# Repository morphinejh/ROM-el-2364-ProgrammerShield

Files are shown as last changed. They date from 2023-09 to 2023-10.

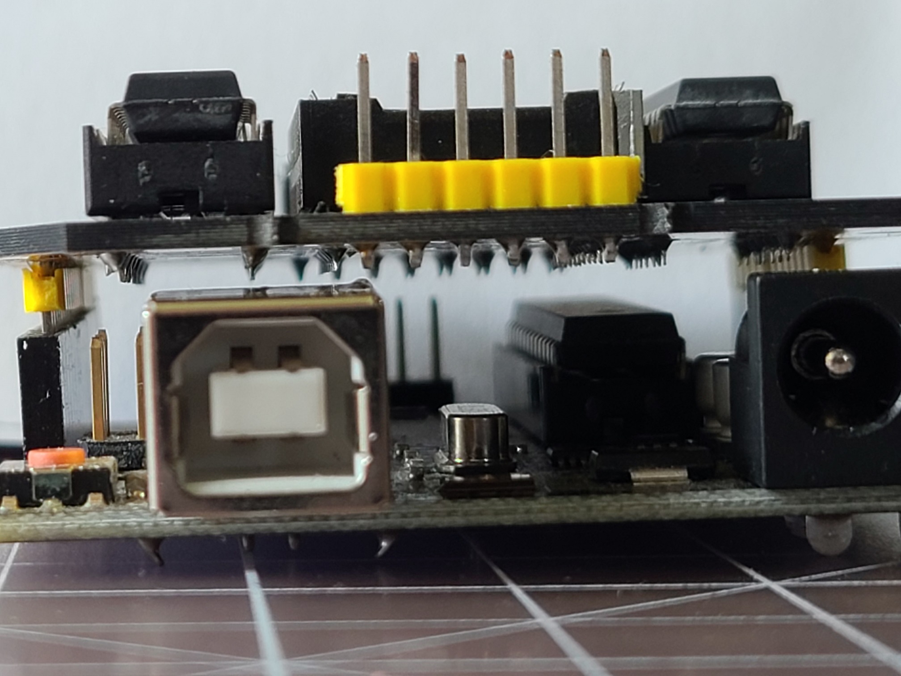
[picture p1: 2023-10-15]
Photos/ROM-el_2364_ClosUp.jpg

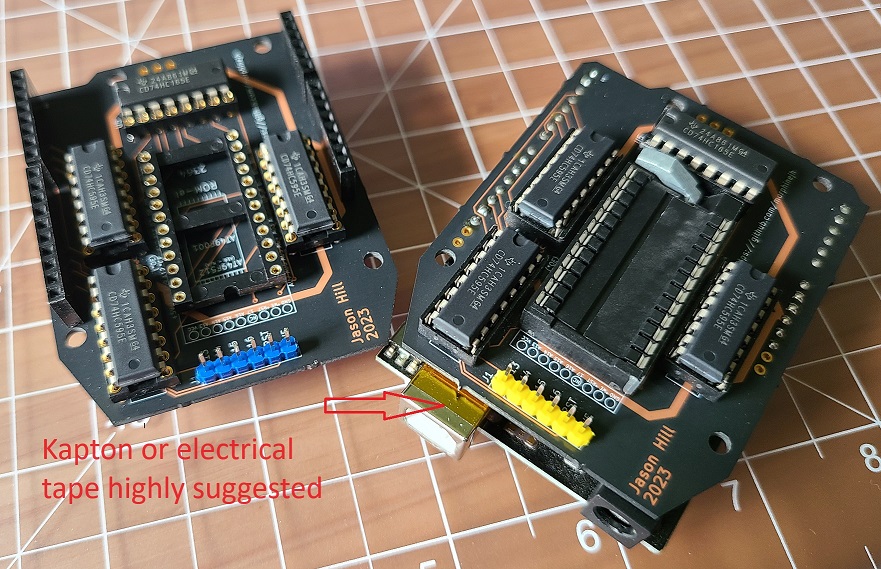
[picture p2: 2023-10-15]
Photos/ROM-el_2364 ProgrammerShield .jpg

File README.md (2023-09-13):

# Arduino Shield Programmer for ROM-el 2364
## Updates / Changes September 2023
* Added schematic for Arduino Shield
    * Test on: Duemilanove, Uno R3, and Mega R3
* Updated Arduino code and Python script data types to extend them to 32-bits for AT49F001 which has 17-bit addressing for the full range.
    * Added basic time duration to displayed output
    * Pin header to attach address
* Tested on Windows and Linux with Python 3
    * Comm port address is now a variable
* [Shared on OSH park](https://oshpark.com/shared_projects/amO60ueQ)

# ROM-el 2364 Programmer

This is an Arduino sketch and companion Python application to read from and write to ROM-el 2364 devices that (as of June 2018) ship with the AT49F512 EEPROM chip. It should, however ,also work with the AT49F001 EEPROM that was originally shipped on the ROM-el 2364.

The Python script was written and tested on a Linux system, and may need some tweaks to run in Windows environments, such as changing the serial port in the init_arduino() routine from /dev/ttyACM0 to, i.e. COM1.

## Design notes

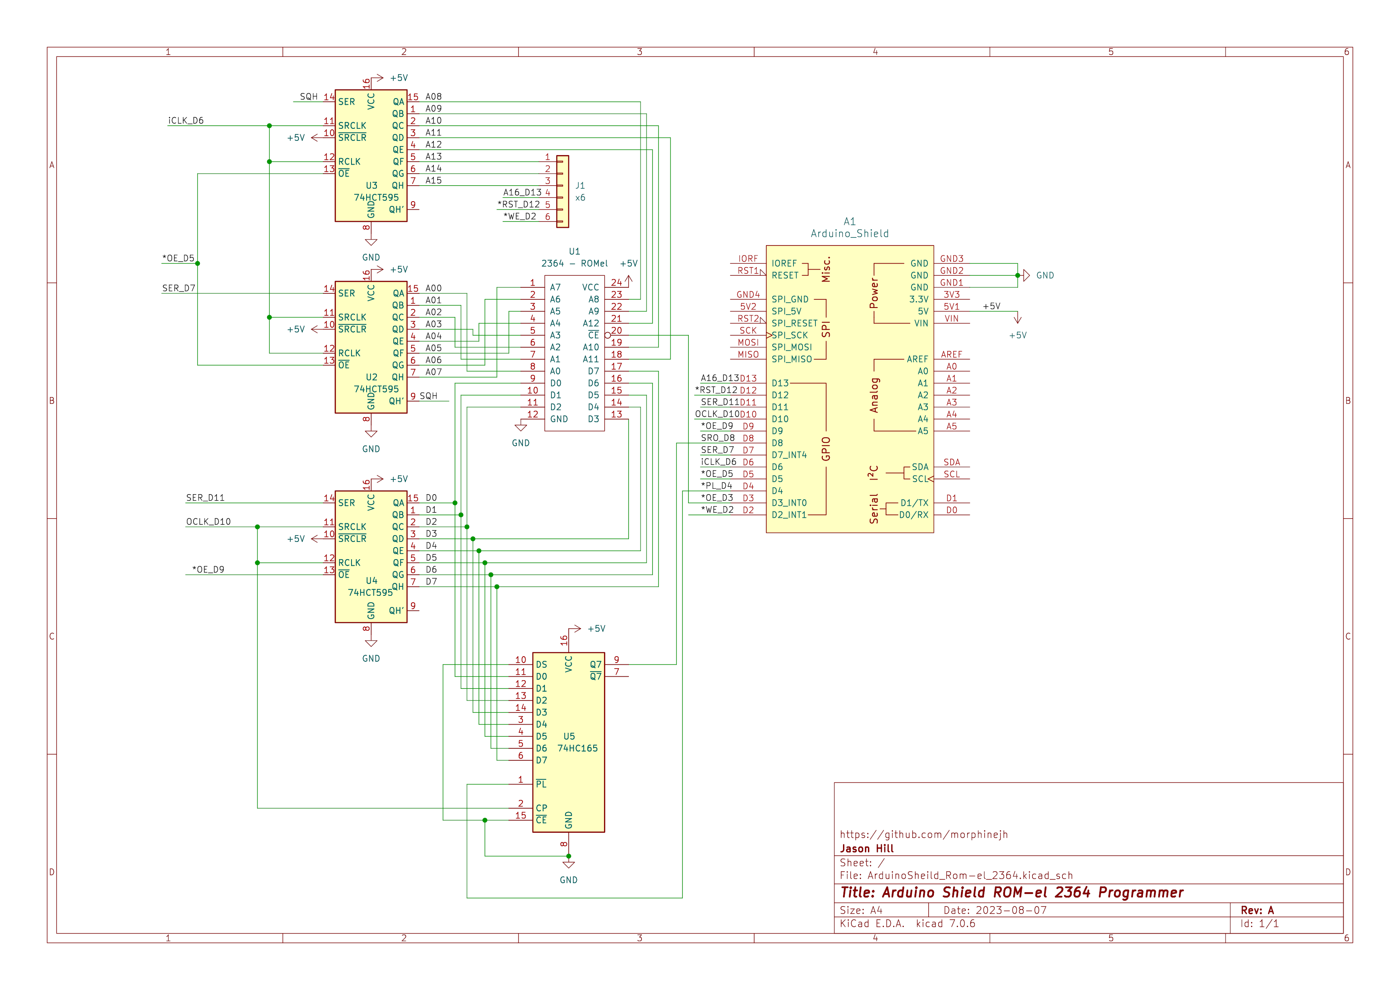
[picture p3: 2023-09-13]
ArduinoSheild_Schematic.png

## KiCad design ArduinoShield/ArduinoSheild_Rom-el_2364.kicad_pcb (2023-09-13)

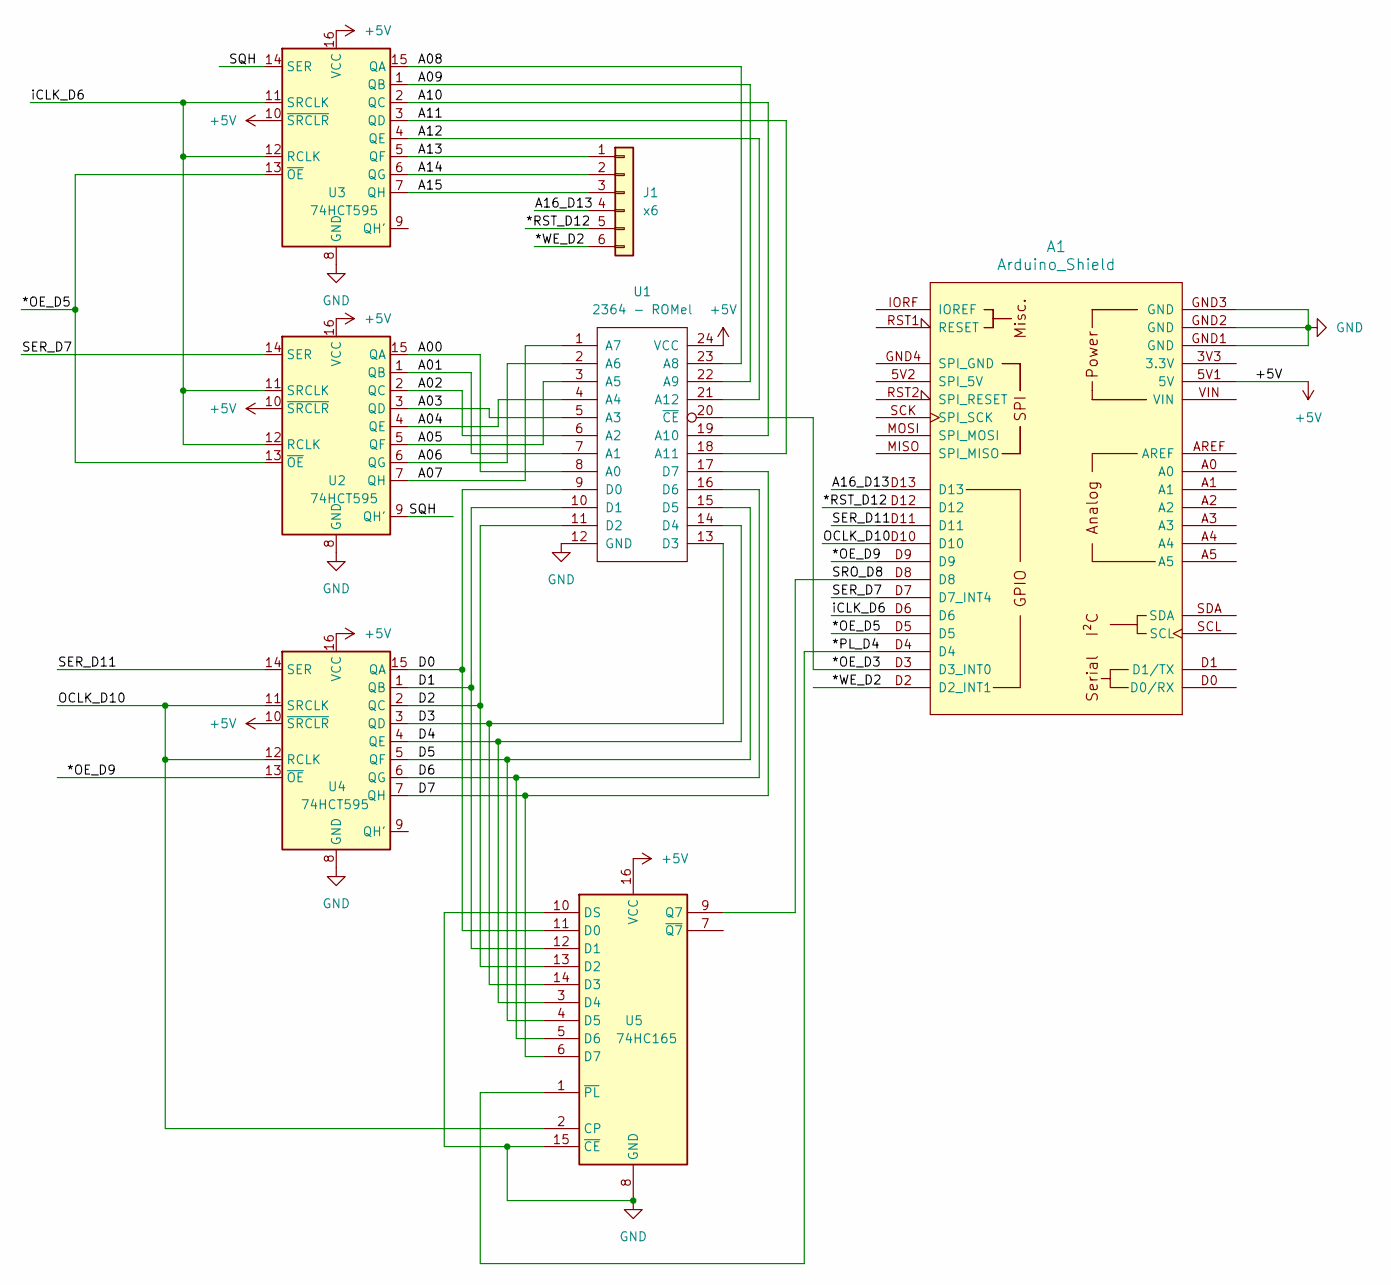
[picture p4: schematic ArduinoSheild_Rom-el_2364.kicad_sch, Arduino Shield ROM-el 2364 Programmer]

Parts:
A1: Arduino_Shield; Arduino_Leonardo_Shield
J1: x6; PinHeader_1x06_P2.54mm_Vertical
U1: 2364 - ROMel; DIP-24_W15.24mm-Notch
U2, U3, U4: 74HCT595; DIP-16_W7.62mm
U5: 74HC165; DIP-16_W7.62mm

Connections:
+5V: A1.5V1 (5V), U1.24 (VCC), U2.10 (~SRCLR), U2.16 (VCC), U3.10 (~SRCLR), U3.16 (VCC), U4.10 (~SRCLR), U4.16 (VCC), U5.16 (VCC)
/*CE_D3: A1.D3 (D3_INT0), U1.20 (~CE)
/*OE_D5: A1.D5, U2.13 (~OE), U3.13 (~OE)
/*OE_D9: A1.D9, U4.13 (~OE)
/*PL_D4: A1.D4, U5.1 (~PL)
/*RST_D12: A1.D12, J1.5
/*WE_D2: A1.D2 (D2_INT1), J1.6
/A00: U1.8 (A0), U2.15 (QA)
/A01: U1.7 (A1), U2.1 (QB)
/A02: U1.6 (A2), U2.2 (QC)
/A03: U1.5 (A3), U2.3 (QD)
/A04: U1.4 (A4), U2.4 (QE)
/A05: U1.3 (A5), U2.5 (QF)
/A06: U1.2 (A6), U2.6 (QG)
/A07: U1.1 (A7), U2.7 (QH)
/A08: U1.23 (A8), U3.15 (QA)
/A09: U1.22 (A9), U3.1 (QB)
/A10: U1.19 (A10), U3.2 (QC)
/A11: U1.18 (A11), U3.3 (QD)
/A12: U1.21 (A12), U3.4 (QE)
/A13: J1.1, U3.5 (QF)
/A14: J1.2, U3.6 (QG)
/A15: J1.3, U3.7 (QH)
/A16_D13: A1.D13, J1.4
/D0: U1.9 (D0), U4.15 (QA), U5.11 (D0)
/D1: U1.10 (D1), U4.1 (QB), U5.12 (D1)
/D2: U1.11 (D2), U4.2 (QC), U5.13 (D2)
/D3: U1.13 (D3), U4.3 (QD), U5.14 (D3)
/D4: U1.14 (D4), U4.4 (QE), U5.3 (D4)
/D5: U1.15 (D5), U4.5 (QF), U5.4 (D5)
/D6: U1.16 (D6), U4.6 (QG), U5.5 (D6)
/D7: U1.17 (D7), U4.7 (QH), U5.6 (D7)
/OCLK_D10: A1.D10, U4.11 (SRCLK), U4.12 (RCLK), U5.2 (CP)
/SER_D7: A1.D7 (D7_INT4), U2.14 (SER)
/SER_D11: A1.D11, U4.14 (SER)
/SQH: U2.9 (QH'), U3.14 (SER)
/SRO_D8: A1.D8, U5.9 (Q7)
/iCLK_D6: A1.D6, U2.11 (SRCLK), U2.12 (RCLK), U3.11 (SRCLK), U3.12 (RCLK)
GND: A1.GND1 (GND), A1.GND2 (GND), A1.GND3 (GND), U1.12 (GND), U2.8 (GND), U3.8 (GND), U4.8 (GND), U5.8 (GND), U5.10 (DS), U5.15 (~CE)

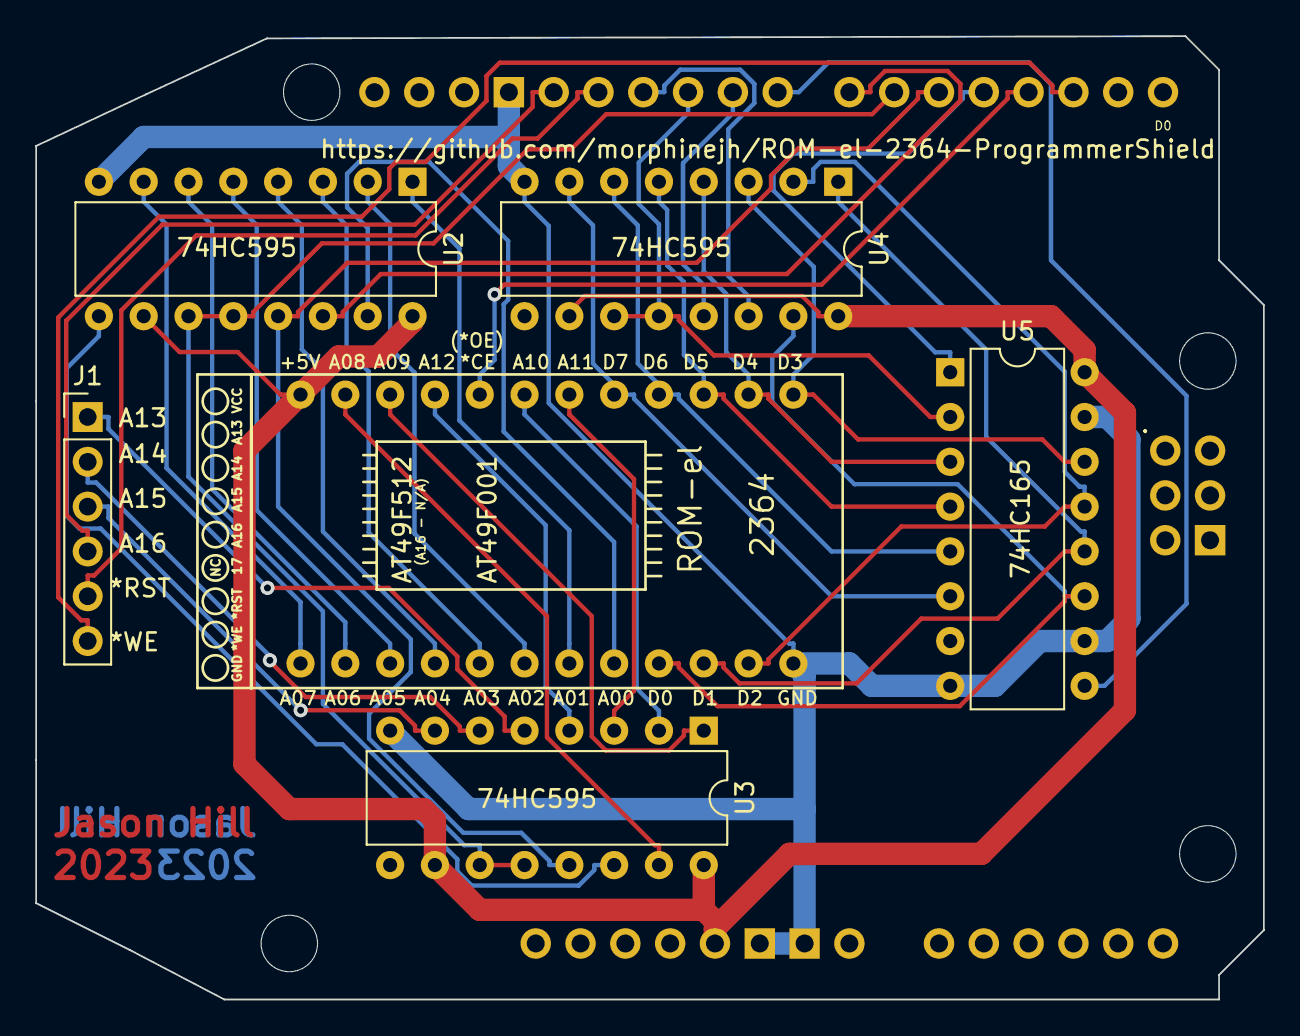
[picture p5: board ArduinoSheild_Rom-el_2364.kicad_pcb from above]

Board: 2 copper layers, 69.6 x 54.6 mm, 7 parts (0 on the bottom side), 39 nets.

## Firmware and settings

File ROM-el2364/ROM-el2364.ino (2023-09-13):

#include "ROM-el2364.hpp"

Mode mode = READ;

void printMessage(String message){
  Serial.write(message.length()+2);
  Serial.println(message);
}

void setup() {
  pinMode(ADDROE, OUTPUT);
  digitalWrite(ADDROE, HIGH);
  pinMode(ADDRCLK, OUTPUT);
  digitalWrite(ADDRCLK, LOW);
  pinMode(ADDRSER, OUTPUT);
  digitalWrite(ADDRSER, LOW);
  pinMode(DATAINOE, OUTPUT);
  digitalWrite(DATAINOE, LOW);
  pinMode(DATAOUTOE, OUTPUT);
  digitalWrite(DATAOUTOE, HIGH);
  pinMode(DATACLK, OUTPUT);
  digitalWrite(DATACLK, LOW);
  pinMode(DATAOUTSER, OUTPUT);
  digitalWrite(DATAOUTSER, LOW);
  pinMode(DATAINSER, INPUT_PULLUP);
  pinMode(EEPROMOE, OUTPUT);
  digitalWrite(EEPROMOE, HIGH);
  pinMode(EEPROMWE, OUTPUT);
  digitalWrite(EEPROMWE, HIGH);

  pinMode(RSTROMEL, OUTPUT);
  digitalWrite(RSTROMEL, HIGH);
  pinMode(ADDR16, OUTPUT);
  digitalWrite(ADDR16, HIGH);

  Serial.begin(115200);
  Serial.setTimeout(3000);
  Serial.print("INIT");
  //Let's do some byte transfers!
}

void setReadMode(){
  if( mode == READ )
    return;
  //Disable shift register (write)
  DATAOUTOE_Set(HIGH);//digitalWrite(DATAOUTOE, HIGH);
  mode = READ;
}

void setWriteMode(){
  if( mode == WRITE )
    return;
  //Disable shift-in register (read)
  DATAINOE_Set(LOW);//digitalWrite(DATAINOE, LOW);
  mode = WRITE;
}

//Shift byte out to SN74HC595 (with tied data lines)
void shiftByteOut(byte data, bool noclock, int clkpin, int serpin, int oepin)
{
  if( oepin == DATAOUTOE )
    digitalWrite(DATAOUTOE, HIGH);
  else
    digitalWrite(oepin, HIGH);

  byte tmpdata = data;

  //Shift MSB-first
  for ( int i = 0; i < 8; i++ )
  {
    digitalWrite(serpin, tmpdata >> 7);
    digitalWrite(clkpin, HIGH);
    digitalWrite(clkpin, LOW);
    tmpdata = tmpdata << 1;
  }
  digitalWrite(serpin, LOW);
  //With tied clock lines, an additional clock pulse is necessary after shifting
  //the very last bit to all shift registers in order to output expected data.
  if(! noclock)
  {
    //Additional clock due to tied RCLK/SRCLK lines
    digitalWrite(clkpin, HIGH);
    digitalWrite(clkpin, LOW);
  }
  if( oepin == DATAOUTOE )
    digitalWrite(DATAOUTOE, LOW);
  else
    digitalWrite(oepin, LOW);
}

//Shift byte in from SN74HC165
uint8_t shiftByteIn(int clkpin, int serpin, int latchpin, short bits = 8){//return shiftByteIn(DATACLK, DATAINSER, DATAINOE, bits);
  uint8_t input = 0;
  DATACLK_Set(HIGH);//digitalWrite(clkpin, HIGH);

  if( latchpin == DATAINOE )
    DATAINOE_Set(LOW);//digitalWrite(DATAINOE, LOW);
  else
    digitalWrite(latchpin, LOW);

  if( latchpin == DATAINOE )
    DATAINOE_Set(HIGH);//digitalWrite(DATAINOE, HIGH);
  else
    digitalWrite(latchpin, HIGH);
    
  //Data shift in MSB-first
  for ( int i = 0; i < bits; i++ ){
    DATACLK_Set(HIGH);//digitalWrite(clkpin, HIGH);
    //Don't clock first, 74HC165 outputs first byte as soon as latch goes high
    __builtin_avr_delay_cycles(5);//TODO: Possible less delay
    input |= DATAINSER_Read() << ((bits-1)-i);//input |= digitalRead(serpin) << ((bits-1)-i);
    DATACLK_Set(LOW);//digitalWrite(clkpin, LOW);
  }
  DATAINOE_Set(LOW);//digitalWrite(DATAINOE, LOW);
  return input;
}

//Write to address lines
void shiftAddress(uint32_t addrin){
  uint16_t addr = addrin & 0x0000FFFF;
  uint8_t out[2];

  out[0]=(addr>>8)&0xFF;
  out[1]=0xFF&addr;

  if(addrin > 0xFFFF){
    digitalWrite(ADDR16,HIGH);
  }
  else{
    digitalWrite(ADDR16,LOW);
  }

  shiftByteOut(out[0], true, ADDRCLK, ADDRSER, ADDROE);
  shiftByteOut(out[1], false, ADDRCLK, ADDRSER, ADDROE);
}

//Write to data lines
void shiftData(uint8_t data){
  setWriteMode();
  shiftByteOut(data, false, DATACLK, DATAOUTSER, DATAOUTOE);
}

//Shift data lines in
//Arguments:
//bits: How many bits to shift in (useful in waitForToggleBit() so that cycles
//      aren't wasted shifting in bits we don't care about.)
uint8_t shiftInData(short bits = 8){
  setReadMode();
  return shiftByteIn(DATACLK, DATAINSER, DATAINOE, bits);
}

//Never could get this to work properly, but waitForToggleBit() works, so...
/*void dataPoll(unsigned short addr, byte data)
{
  setReadMode();
  digitalWrite(EEPROMOE, LOW);
  __builtin_avr_delay_cycles(1);
  bool validdata = data & 0x80;
  while( true )
  {
    digitalWrite(EEPROMOE, LOW);
    byte addressread = shiftInData();
    addressread &= 0x80;
    digitalWrite(EEPROMOE, HIGH);
    if( addressread != validdata )
      continue;
    else
      break;
  }
}*/

//Implementation of "AC Load" from AT49F512 datasheet
void ACLoad(uint32_t addrin, uint8_t data){
  setWriteMode();
  EEPROMOE_Set(HIGH);//digitalWrite(EEPROMOE, HIGH);
  shiftAddress(addrin);
  EEPROMWE_Set(LOW);//digitalWrite(EEPROMWE, LOW);
  __builtin_avr_delay_cycles(2); //Delay an extra cycle to satisfy tWP = 90ns
  shiftData(data);
  EEPROMWE_Set(HIGH);//digitalWrite(EEPROMWE, HIGH);
  __builtin_avr_delay_cycles(2); //Delay cycles to satisfy tWPH = 90ns
}

//Implementation of "AC Read" from AT49F512 datasheet
uint8_t ACRead(uint32_t addrin){
  setReadMode();
  EEPROMWE_Set(HIGH);//digitalWrite(EEPROMWE, HIGH);
  shiftAddress(addrin);
  EEPROMOE_Set(LOW);//digitalWrite(EEPROMOE, LOW);
  __builtin_avr_delay_cycles(2);
  uint8_t input = shiftInData();
  EEPROMOE_Set(HIGH);//digitalWrite(EEPROMOE, HIGH);
  return input;
}

uint8_t writeAddress(uint32_t addrin, uint8_t data){
  ACLoad(0x5555, 0xAA);
  ACLoad(0x2AAA, 0x55);
  ACLoad(0x5555, 0xA0);
  ACLoad(addrin, data);
  digitalWrite(EEPROMOE, LOW);
  waitForToggleBit();
  return 0x00;
}

void eraseChip(){
  digitalWrite(EEPROMOE, HIGH);
  ACLoad(0x5555, 0xAA);
  ACLoad(0x2AAA, 0x55);
  ACLoad(0x5555, 0x80);
  ACLoad(0x5555, 0xAA);
  ACLoad(0x2AAA, 0x55);
  ACLoad(0x5555, 0x10);
  waitForToggleBit();
}

//This Atmel chip, during a program or erase cycle will implement a "toggle bit."
//Per the datasheet:
//"During a program or erase operation, successive attempts to read data from the device
//will result in I/O6 toggling between one and zero. Once the program cycle has completed,
//I/O6 will stop toggling and valid data will be read."
void waitForToggleBit(){
  return;
  uint8_t initial = 0;
  uint8_t nextbit = 0;
  setReadMode();
  EEPROMOE_Set(LOW);//digitalWrite(EEPROMOE, LOW);
  //Store bit 7 (I/O 6)
  //byte initial = shiftInData(2) & 0x40;
  initial = shiftInData(2) & 0x40;
  while( true ){
    EEPROMOE_Set(HIGH);//digitalWrite(EEPROMOE, HIGH);

    //Needs to be high for 150ns, One cycle is ~62.5ns
    //At 16MHz this is a delay of ~187.5ns
    //However, a digital write already takes 3.4us = 3,400ns!!
    //dont' wait.
    __builtin_avr_delay_cycles(3);
    EEPROMOE_Set(LOW);//digitalWrite(EEPROMOE, LOW);
    
    //Check bit 7 again
    nextbit = shiftInData(2) & 0x40;
    //If bit 7 is stable, the write/erase has finished.
    if( nextbit == initial )
      break;
    else
      initial = nextbit;
  }
}

void verifyRange(uint32_t startaddr, uint32_t endaddr){
  for (uint32_t i = startaddr; i <= endaddr; i++ )
  {
    Serial.write(0x01);
    Serial.write(ACRead(i));
  }
}

void loop() {
  uint8_t data;
  uint8_t serialbuffer[10];
  memset(serialbuffer, 0x00, sizeof(serialbuffer));
  /*Protocol definition:
  <packet> ::= <length> <command> | <length> <command> <data>
  <data> ::= <address> | <address> <byte>
  <command> ::= 'R' | 'W' | 'E' comment <erase command>
  <byte> ::= <a single byte>
  <address> ::= <4-byte address>
  <length> ::= <1-byte length of packet (excluding length byte itself)>

  This allows two modes of operation:
  In the first mode (i.e. <length>R\x01\x00), the controlling application
  specifies all addresses (and, in write mode, the data to be stored). In the
  second mode (i.e. <length>R) bytes are read/written sequentially, using the
  address variable stored on the Arduino.

  If a program wanted to read 8 bytes starting at 0x0100, either of these
  command sets could be used:
  R\x01\x00
  R\x01\x01
  R\x01\x02
  R\x01\x03
  R\x01\x04
  R\x01\x05
  R\x01\x06
  R\x01\x07

  or

  R\x01\x00 //Read 7 sequential addresses
  R
  R
  R
  R
  R
  R
  R
  */

  while ( !Serial.available() )
    continue;

  Serial.readBytes(serialbuffer, 1);
  uint8_t packetlen = serialbuffer[0];

  while ( Serial.available() != packetlen )
    continue;

  Serial.readBytes(serialbuffer, packetlen);

  //Read mode
  if ( serialbuffer[0] == 'R' ){
    setReadMode();
    //No address given
    if ( packetlen == 1 ){
      data = ACRead(address);
      Serial.write(0x01);
      Serial.write(data);
    }
    //Address given
    else{
      uint32_t packetaddress = serialbuffer[1];
      packetaddress <<= 8;
      packetaddress += serialbuffer[2];
      packetaddress <<= 8;
      packetaddress += serialbuffer[3];
      packetaddress <<= 8;
      packetaddress += serialbuffer[4];
      address = packetaddress;

      data = ACRead(packetaddress);
      Serial.write(0x01);
      Serial.write(data);
    }
    address++;
  }
  //Write mode
  else if ( serialbuffer[0] == 'W' ){
    unsigned short retval;
    setWriteMode();
    //No address given
    if ( packetlen == 2 ){
      retval = writeAddress(address, serialbuffer[1]);
    }
    //Address given
    else{
      uint32_t packetaddress = serialbuffer[1];
      packetaddress <<= 8;
      packetaddress += serialbuffer[2];
      packetaddress <<= 8;
      packetaddress += serialbuffer[3];
      packetaddress <<= 8;
      packetaddress += serialbuffer[4];
      address = packetaddress;

      uint8_t retval = writeAddress(address, serialbuffer[5]);
    }
    Serial.write(0x01);
    Serial.write(retval);
    address++;
  }
  //Erase mode
  else if ( serialbuffer[0] == byte('E') ){
    mode = ERASE;
    eraseChip();
    Serial.write(0x01);
    Serial.write(0x01);
  }
  //Verify mode (UNTESTED)
  else{
    mode = VERIFY;
    unsigned short startAddress = serialbuffer[1] << 8;
    startAddress += serialbuffer[2];
    unsigned short endAddress = serialbuffer[3] << 8;
    endAddress = serialbuffer[4];
    verifyRange(startAddress, endAddress);
  }
}

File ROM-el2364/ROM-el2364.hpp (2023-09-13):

//EEPROMCE is always low!
/*-----------------------------*/
const int EEPROMWE = 2;   //PD2
const int EEPROMOE = 3;   //PD3
/*-----------------------------*/
const int ADDROE = 5;     //PD5
const int ADDRCLK = 6;    //PD6
const int ADDRSER = 7;    //PD7
/*-----------------------------*/
const int DATAINOE = 4;   //PD4
const int DATAOUTOE = 9;  //PB1
const int DATACLK = 10;   //PB2
const int DATAOUTSER = 11;//PB3
const int DATAINSER = 8;  //PB0
/*-----------------------------*/
const int RSTROMEL = 12;  //PB6
const int ADDR16 = 13;    //PB6
/*-----------------------------*/
const int FAST = 0;
uint32_t address = 0x00000000;

enum Mode {
  READ = LOW,
  WRITE = HIGH,
  ERASE,
  VERIFY
};

/*--------------EEPROM PINS--------------------*/
inline void EEPROMWE_Set(bool state){/*EEPROMWE = 2 //PD2*/
    if(state!=LOW){
      if(FAST)
        PORTD |= 0b00000100;
      else
        digitalWrite(EEPROMWE, HIGH);
    }
    else{
      if(FAST)
        PORTD &= 0b11111011;
      else
        digitalWrite(EEPROMWE,LOW);
    }
}
inline void EEPROMOE_Set(bool state){/*EEPROMOE = 3;   //PD3*/
   if(state!=LOW){
    if(FAST)
      PORTD |= 0b00001000;
    else
      digitalWrite(EEPROMOE,HIGH);
   }
   else{
    if(FAST)
      PORTD &= 0b11110111;
    else
      digitalWrite(EEPROMOE,LOW);
   }
}
/*--------------Addr PINS----------------------*/
inline void ADDROE_Set(bool state){/*ADDROE = 5;   //PD5*/
   if(state!=LOW){
    if(FAST)
      PORTD |= 0b00100000;
    else
      digitalWrite(ADDROE,HIGH);
   }
   else{
    if(FAST)
      PORTD &= 0b11011111;
    else
      digitalWrite(ADDROE,LOW);
   }
}
inline void ADDRCLK_Set(bool state){/*ADDRCLK = 6;   //PD6*/
   if(state!=LOW){
    if(FAST)
      PORTD |= 0b01000000;
    else
      digitalWrite(ADDRCLK,HIGH);
   }
   else{
    if(FAST)
      PORTD &= 0b10111111;
    else
      digitalWrite(ADDRCLK, LOW);
   }
}
inline void ADDRSER_Set(bool state){/*ADDRSER = 7;   //PD7*/
   if(state!=LOW){
    if(FAST)
      PORTD |= 0b10000000;
    else
      digitalWrite(ADDRSER,HIGH);
   }
   else{
    if(FAST)
      PORTD &= 0b01111111;
    else
      digitalWrite(ADDRSER,LOW);
   }
}
/*--------------Dat PINS------------------------*/
inline void DATAINOE_Set(bool state){/*DATAINOE = 4;   PD4*/
   if(state!=LOW){
    if(FAST)
      PORTD |= 0b00010000;
    else
      digitalWrite(DATAINOE,HIGH);
   }
   else{
    if(FAST)
      PORTD &= 0b11101111;
    else
      digitalWrite(DATAINOE,LOW);
   }
}
inline void DATAOUTOE_Set(bool state){/* DATAOUTOE = 9;  PB1*/
   if(state!=LOW){
    if(FAST)
      PORTB |= 0b00000010;
    else
      digitalWrite(DATAOUTOE,HIGH);
   }
   else{
    if(FAST)
      PORTB &= 0b11111101;
    else
      digitalWrite(DATAOUTOE,LOW);
   }
}
inline void DATACLK_Set(bool state){/*DATACLK = 10;   PB2*/
   if(state!=LOW){
    if(FAST)
      PORTB |= 0b00000100;
    else
      digitalWrite(DATACLK,HIGH);
   }
   else{
    if(FAST)
      PORTB &= 0b11111011;
    else
      digitalWrite(DATACLK,LOW);
   }
}
inline void DATAOUTSER_Set(bool state){/*DATAOUTSER = 11;//PB3*/
   if(state!=LOW){
    if(FAST)
      PORTB |= 0b00001000;
    else
      digitalWrite(DATAOUTSER,HIGH);
   }
   else{
    if(FAST)
      PORTB &= 0b11110111;
    else
      digitalWrite(DATAOUTSER,LOW);
   }
}
inline uint8_t DATAINSER_Read(){/*DATAINSER = 8;  //PB0*/
  uint8_t retVal;
  if(FAST)
    retVal = PINB &= 0b00000001;
  else
    retVal = digitalRead(DATAINSER);

  if(retVal)
    return 1;
  else
    return 0;

}
